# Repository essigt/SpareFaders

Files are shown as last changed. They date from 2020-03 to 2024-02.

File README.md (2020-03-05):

# SpareFaders

A (still work in progress) STM32-BluePill based MA-Style midi controller featuring 60 buttons and 15 faders.

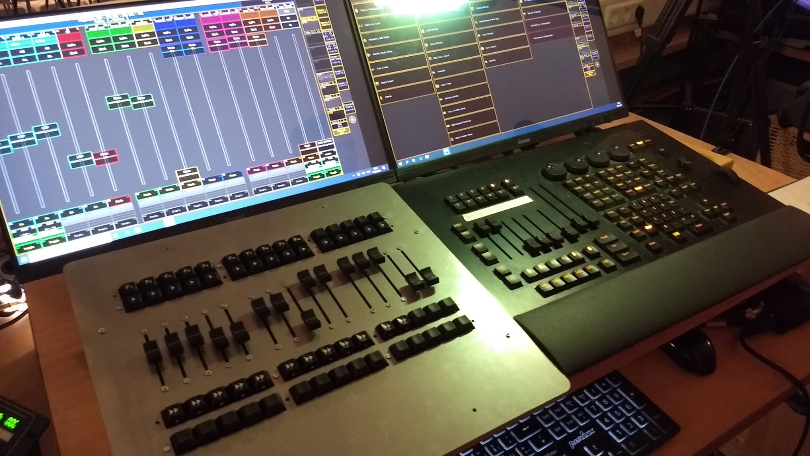
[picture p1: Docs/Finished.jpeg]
Finished prototype


## PCB

The project is made up of two PCB types. A controller PCB and a keys PCB with can be assambled both for the keys above or under the faders.

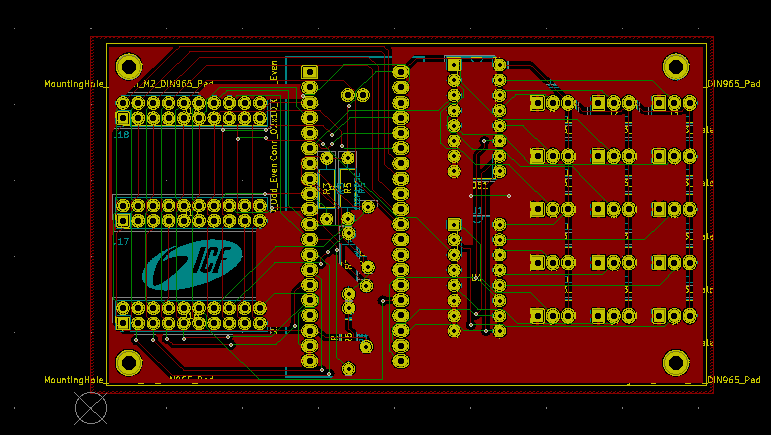
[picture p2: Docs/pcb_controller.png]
Controller PCB


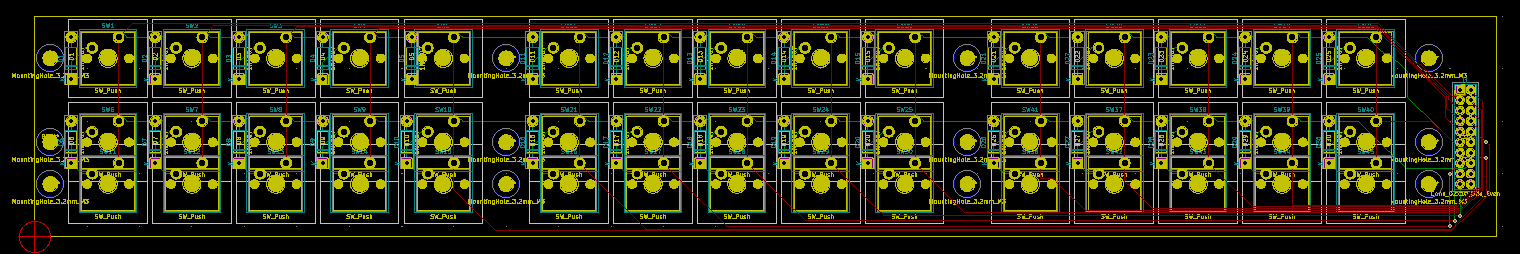
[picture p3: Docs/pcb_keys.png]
Keys PCB


### Assembly

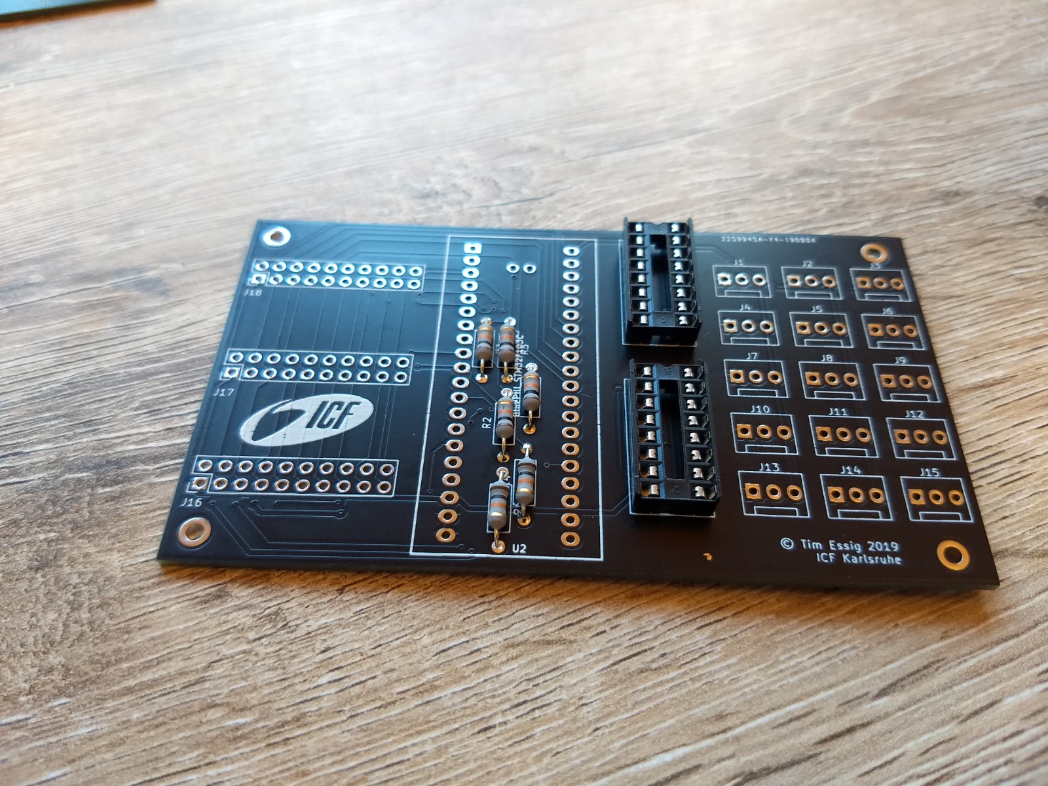
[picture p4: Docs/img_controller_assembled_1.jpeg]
Controller Assembled

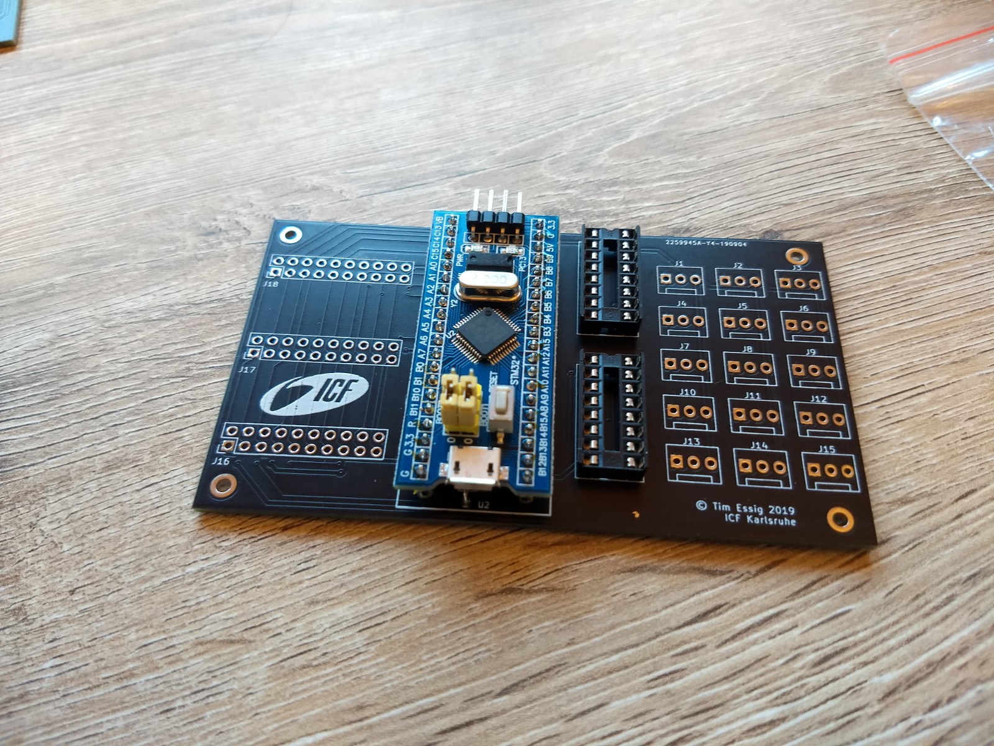
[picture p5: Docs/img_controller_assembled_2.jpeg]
Controller Assembled

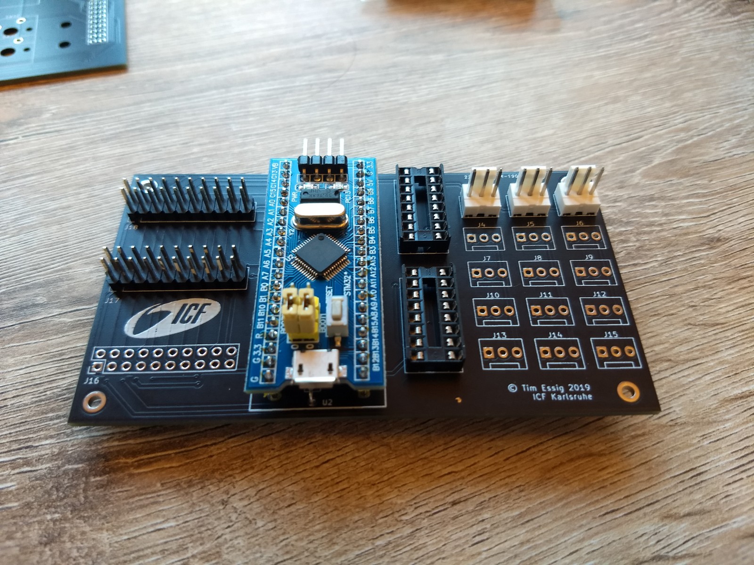
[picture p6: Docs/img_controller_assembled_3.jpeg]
Controller Assembled


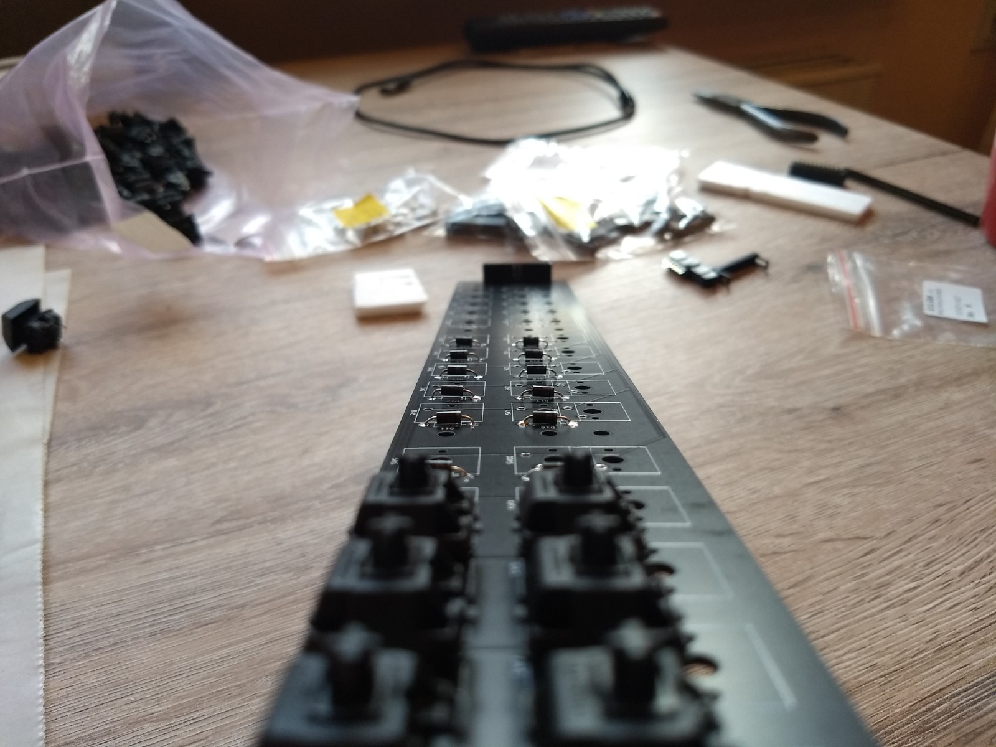
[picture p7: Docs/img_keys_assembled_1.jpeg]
Keys Assembled

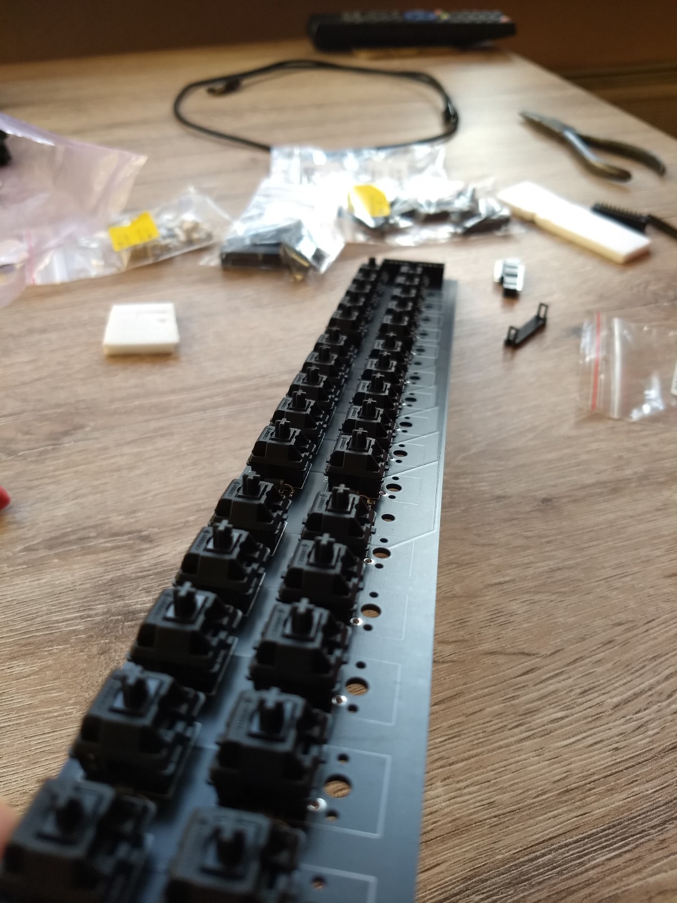
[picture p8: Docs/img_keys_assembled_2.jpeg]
Keys Assembled


## Front Plate

The files for the front plate will be uploaded soon.

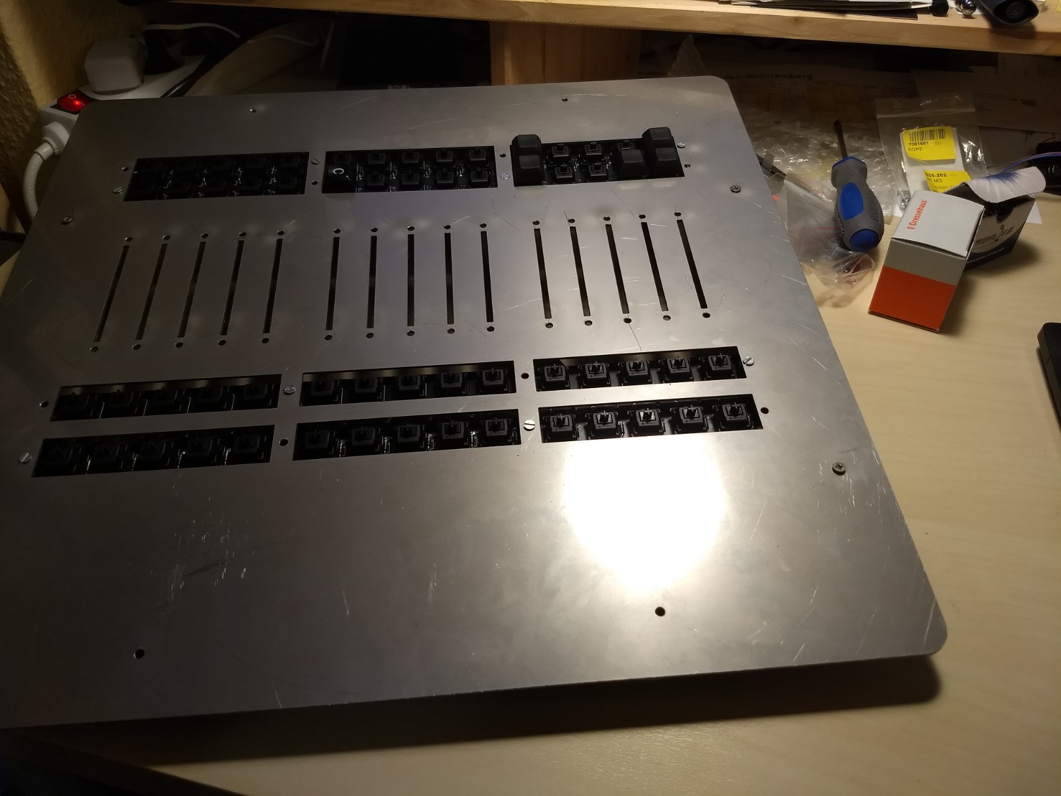
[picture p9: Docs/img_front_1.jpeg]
Front plate


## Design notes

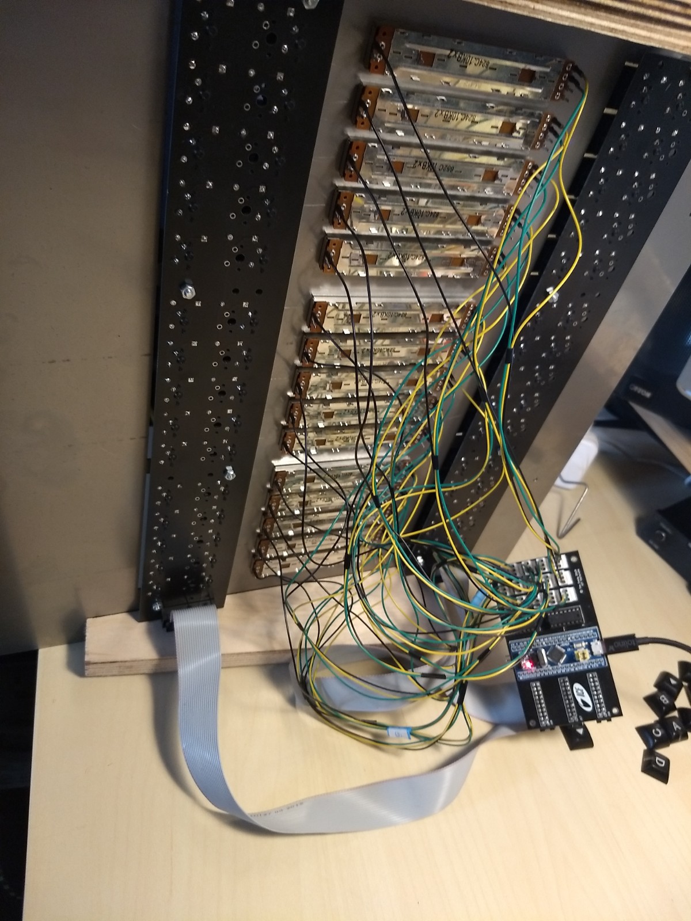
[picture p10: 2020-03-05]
Docs/img_back_1.jpeg

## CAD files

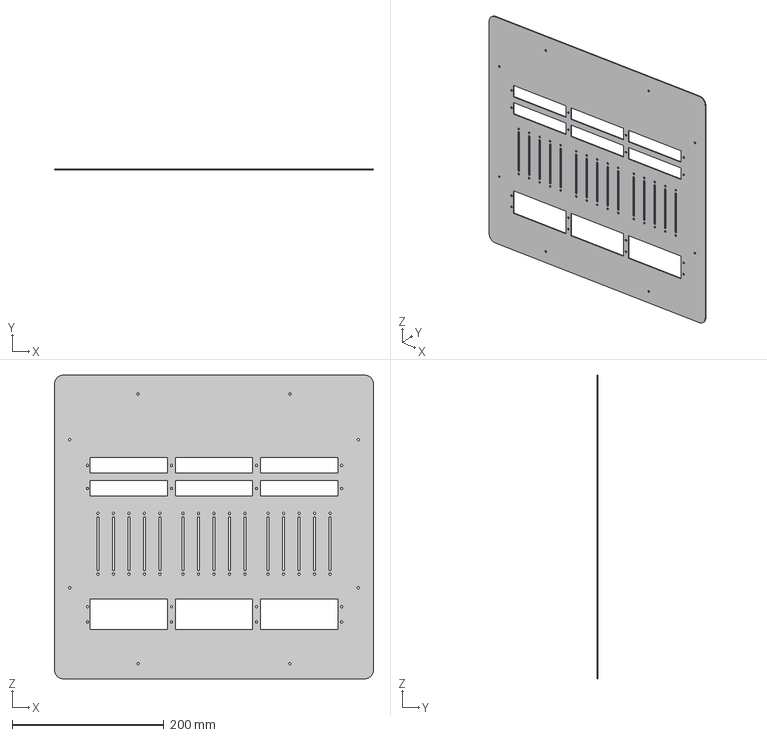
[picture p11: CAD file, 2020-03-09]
Hardware/housing/export/frontplate.step
420.0 x 1.50 x 400.0 mm

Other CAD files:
Hardware/housing/export/frontplate.dxf
Hardware/housing/frontplate.f3d

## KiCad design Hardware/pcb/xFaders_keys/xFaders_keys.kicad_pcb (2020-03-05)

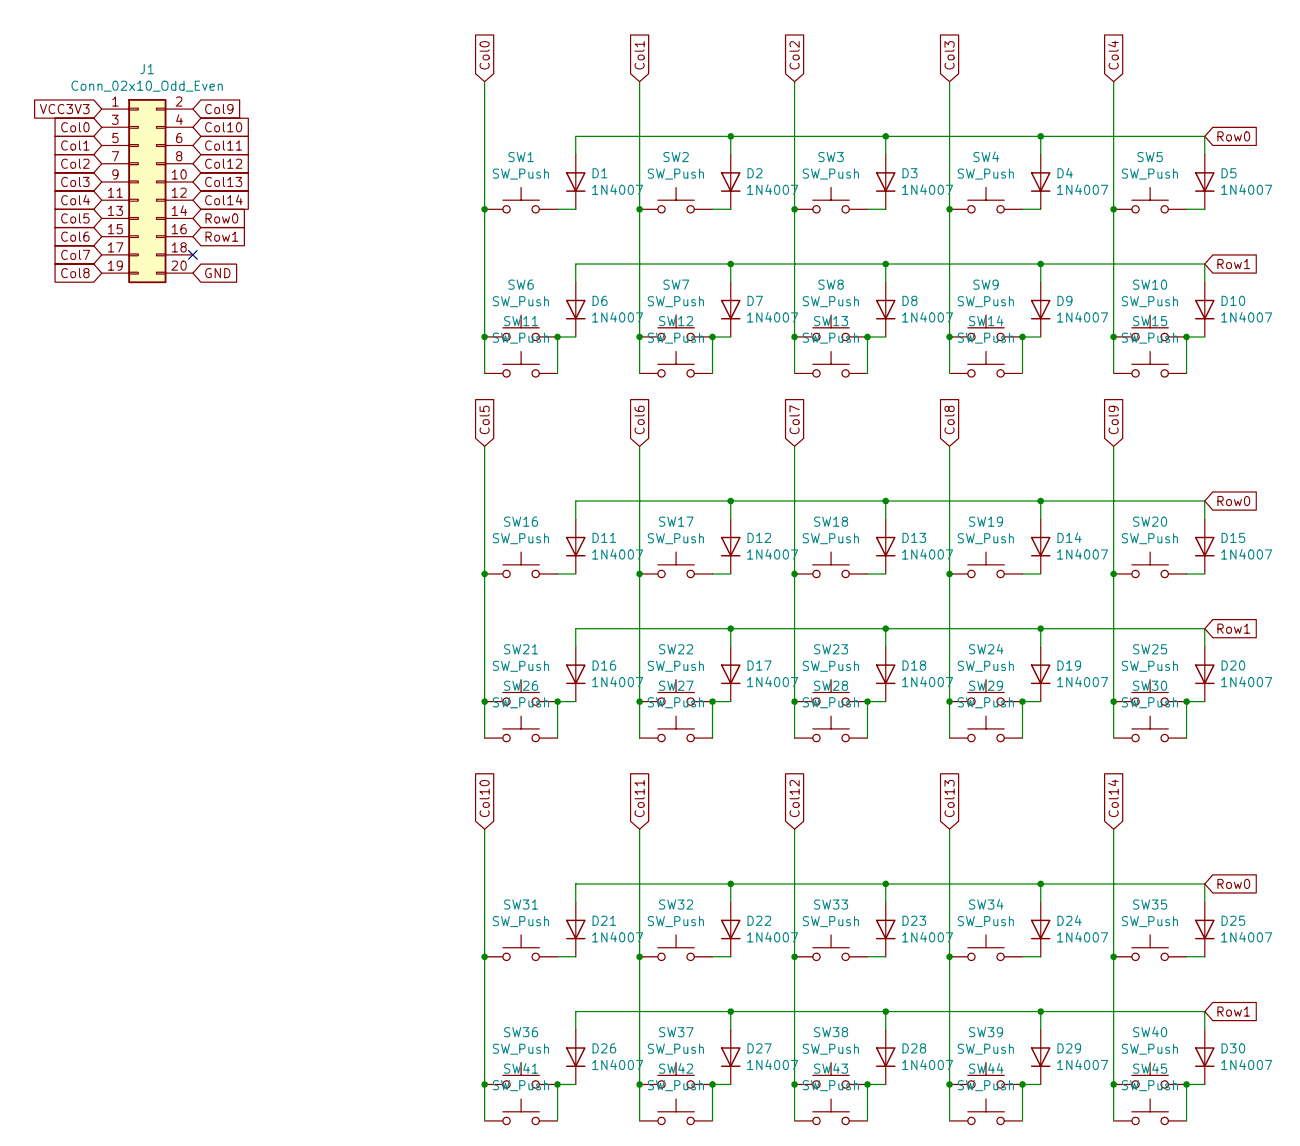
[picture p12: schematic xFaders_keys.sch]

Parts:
D1, D2, D3, D4, D5, D6, D7, D8, D9, D10, D11, D12, D13, D14, D15, D16, D17, D18, D19, D20, D21, D22, D23, D24, D25, D26, D27, D28, D29, D30: 1N4007; D_DO-41_SOD81_P10.16mm_Horizontal
J1: Conn_02x10_Odd_Even; PinHeader_2x10_P2.54mm_Vertical
SW1, SW2, SW3, SW4, SW5, SW6, SW7, SW8, SW9, SW10, SW11, SW12, SW13, SW14, SW15, SW16, SW17, SW18, SW19, SW20, SW21, SW22, SW23, SW24, SW25, SW26, SW27, SW28, SW29, SW30, SW31, SW32, SW33, SW34, SW35, SW36, SW37, SW38, SW39, SW40, SW41, SW42, SW43, SW44, SW45: SW_Push; SW_Cherry_MX_1.00u_PCB

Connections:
Col0: J1.3, SW1.1, SW6.1, SW11.1
Col1: J1.5, SW2.1, SW7.1, SW12.1
Col2: J1.7, SW3.1, SW8.1, SW13.1
Col3: J1.9, SW4.1, SW9.1, SW14.1
Col4: J1.11, SW5.1, SW10.1, SW15.1
Col5: J1.13, SW16.1, SW21.1, SW26.1
Col6: J1.15, SW17.1, SW22.1, SW27.1
Col7: J1.17, SW18.1, SW23.1, SW28.1
Col8: J1.19, SW19.1, SW24.1, SW29.1
Col9: J1.2, SW20.1, SW25.1, SW30.1
Col10: J1.4, SW31.1, SW36.1, SW41.1
Col11: J1.6, SW32.1, SW37.1, SW42.1
Col12: J1.8, SW33.1, SW38.1, SW43.1
Col13: J1.10, SW34.1, SW39.1, SW44.1
Col14: J1.12, SW35.1, SW40.1, SW45.1
GND: J1.20
unnamed: D1.1 (K), SW1.2
unnamed: D2.1 (K), SW2.2
unnamed: D3.1 (K), SW3.2
unnamed: D4.1 (K), SW4.2
unnamed: D5.1 (K), SW5.2
unnamed: D6.1 (K), SW6.2, SW11.2
unnamed: D7.1 (K), SW7.2, SW12.2
unnamed: D8.1 (K), SW8.2, SW13.2
unnamed: D9.1 (K), SW9.2, SW14.2
unnamed: D10.1 (K), SW10.2, SW15.2
unnamed: D11.1 (K), SW16.2
unnamed: D12.1 (K), SW17.2
unnamed: D13.1 (K), SW18.2
unnamed: D14.1 (K), SW19.2
unnamed: D15.1 (K), SW20.2
unnamed: D16.1 (K), SW21.2, SW26.2
unnamed: D17.1 (K), SW22.2, SW27.2
unnamed: D18.1 (K), SW23.2, SW28.2
unnamed: D19.1 (K), SW24.2, SW29.2
unnamed: D20.1 (K), SW25.2, SW30.2
unnamed: D21.1 (K), SW31.2
unnamed: D22.1 (K), SW32.2
unnamed: D23.1 (K), SW33.2
unnamed: D24.1 (K), SW34.2
unnamed: D25.1 (K), SW35.2
unnamed: D26.1 (K), SW36.2, SW41.2
unnamed: D27.1 (K), SW37.2, SW42.2
unnamed: D28.1 (K), SW38.2, SW43.2
unnamed: D29.1 (K), SW39.2, SW44.2
unnamed: D30.1 (K), SW40.2, SW45.2
Row0: D1.2 (A), D2.2 (A), D3.2 (A), D4.2 (A), D5.2 (A), D11.2 (A), D12.2 (A), D13.2 (A), D14.2 (A), D15.2 (A), D21.2 (A), D22.2 (A), D23.2 (A), D24.2 (A), D25.2 (A), J1.14
Row1: D6.2 (A), D7.2 (A), D8.2 (A), D9.2 (A), D10.2 (A), D16.2 (A), D17.2 (A), D18.2 (A), D19.2 (A), D20.2 (A), D26.2 (A), D27.2 (A), D28.2 (A), D29.2 (A), D30.2 (A), J1.16
VCC3V3: J1.1

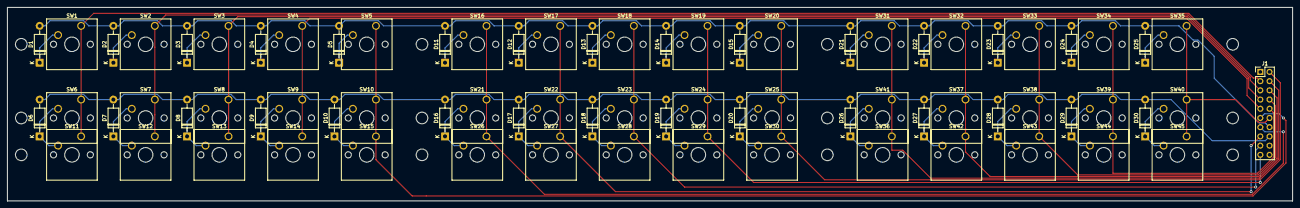
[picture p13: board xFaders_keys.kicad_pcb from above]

Board: 2 copper layers, 354.3 x 53.3 mm, 76 parts (0 on the bottom side), 47 nets.

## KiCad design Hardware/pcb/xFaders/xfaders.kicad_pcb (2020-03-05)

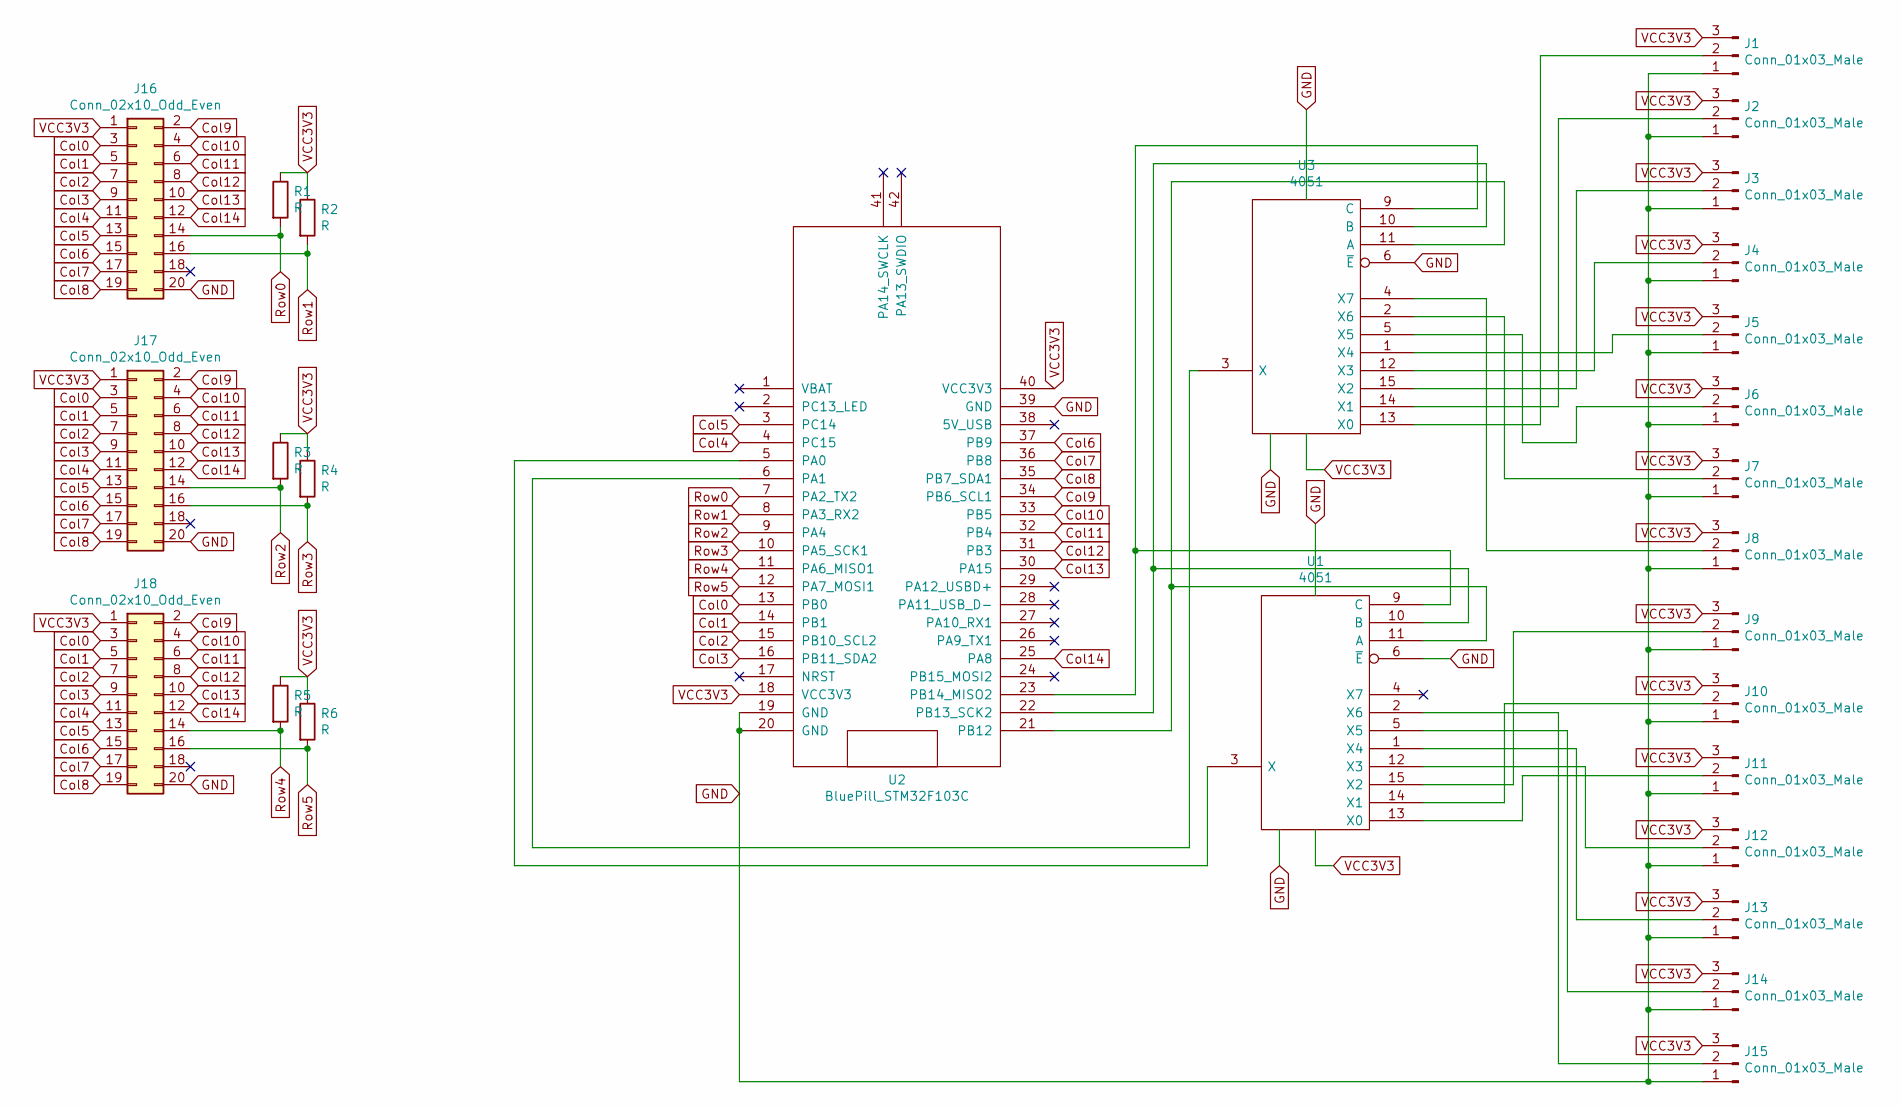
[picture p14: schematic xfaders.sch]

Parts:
J1, J2, J3, J4, J5, J6, J7, J8, J9, J10, J11, J12, J13, J14, J15: Conn_01x03_Male; FanPinHeader_1x03_P2.54mm_Vertical
J16, J17, J18: Conn_02x10_Odd_Even; PinHeader_2x10_P2.54mm_Vertical
R1, R2, R3, R4, R5, R6: R
U1, U3: 4051; DIP-16_W7.62mm_Socket
U2: BluePill_STM32F103C

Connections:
Col0: J16.3, J17.3, J18.3, U2.13 (PB0)
Col1: J16.5, J17.5, J18.5, U2.14 (PB1)
Col2: J16.7, J17.7, J18.7, U2.15 (PB10_SCL2)
Col3: J16.9, J17.9, J18.9, U2.16 (PB11_SDA2)
Col4: J16.11, J17.11, J18.11, U2.4 (PC15)
Col5: J16.13, J17.13, J18.13, U2.3 (PC14)
Col6: J16.15, J17.15, J18.15, U2.37 (PB9)
Col7: J16.17, J17.17, J18.17, U2.36 (PB8)
Col8: J16.19, J17.19, J18.19, U2.35 (PB7_SDA1)
Col9: J16.2, J17.2, J18.2, U2.34 (PB6_SCL1)
Col10: J16.4, J17.4, J18.4, U2.33 (PB5)
Col11: J16.6, J17.6, J18.6, U2.32 (PB4)
Col12: J16.8, J17.8, J18.8, U2.31 (PB3)
Col13: J16.10, J17.10, J18.10, U2.30 (PA15)
Col14: J16.12, J17.12, J18.12, U2.25 (PA8)
GND: J1.1, J2.1, J3.1, J4.1, J5.1, J6.1, J7.1, J8.1, J9.1, J10.1, J11.1, J12.1, J13.1, J14.1, J15.1, J16.20, J17.20, J18.20, U1.6 (~E), U1.7 (VEE), U1.8 (Vss), U2.19 (GND), U2.20 (GND), U2.39 (GND), U3.6 (~E), U3.7 (VEE), U3.8 (Vss)
unnamed: J1.2, U3.13 (X0)
unnamed: J2.2, U3.14 (X1)
unnamed: J3.2, U3.15 (X2)
unnamed: J4.2, U3.12 (X3)
unnamed: J5.2, U3.1 (X4)
unnamed: J6.2, U3.5 (X5)
unnamed: J7.2, U3.2 (X6)
unnamed: J8.2, U3.4 (X7)
unnamed: J9.2, U1.15 (X2)
unnamed: J10.2, U1.14 (X1)
unnamed: J11.2, U1.13 (X0)
unnamed: J12.2, U1.12 (X3)
unnamed: J13.2, U1.1 (X4)
unnamed: J14.2, U1.5 (X5)
unnamed: J15.2, U1.2 (X6)
unnamed: U1.3 (X), U2.5 (PA0)
unnamed: U1.9 (C), U2.23 (PB14_MISO2), U3.9 (C)
unnamed: U1.10 (B), U2.22 (PB13_SCK2), U3.10 (B)
unnamed: U1.11 (A), U2.21 (PB12), U3.11 (A)
unnamed: U2.6 (PA1), U3.3 (X)
Row0: J16.14, R1.2, U2.7 (PA2_TX2)
Row1: J16.16, R2.2, U2.8 (PA3_RX2)
Row2: J17.14, R3.2, U2.9 (PA4)
Row3: J17.16, R4.2, U2.10 (PA5_SCK1)
Row4: J18.14, R5.2, U2.11 (PA6_MISO1)
Row5: J18.16, R6.2, U2.12 (PA7_MOSI1)
VCC3V3: J1.3, J2.3, J3.3, J4.3, J5.3, J6.3, J7.3, J8.3, J9.3, J10.3, J11.3, J12.3, J13.3, J14.3, J15.3, J16.1, J17.1, J18.1, R1.1, R2.1, R3.1, R4.1, R5.1, R6.1, U1.16 (Vdd), U2.18 (VCC3V3), U2.40 (VCC3V3), U3.16 (Vdd)

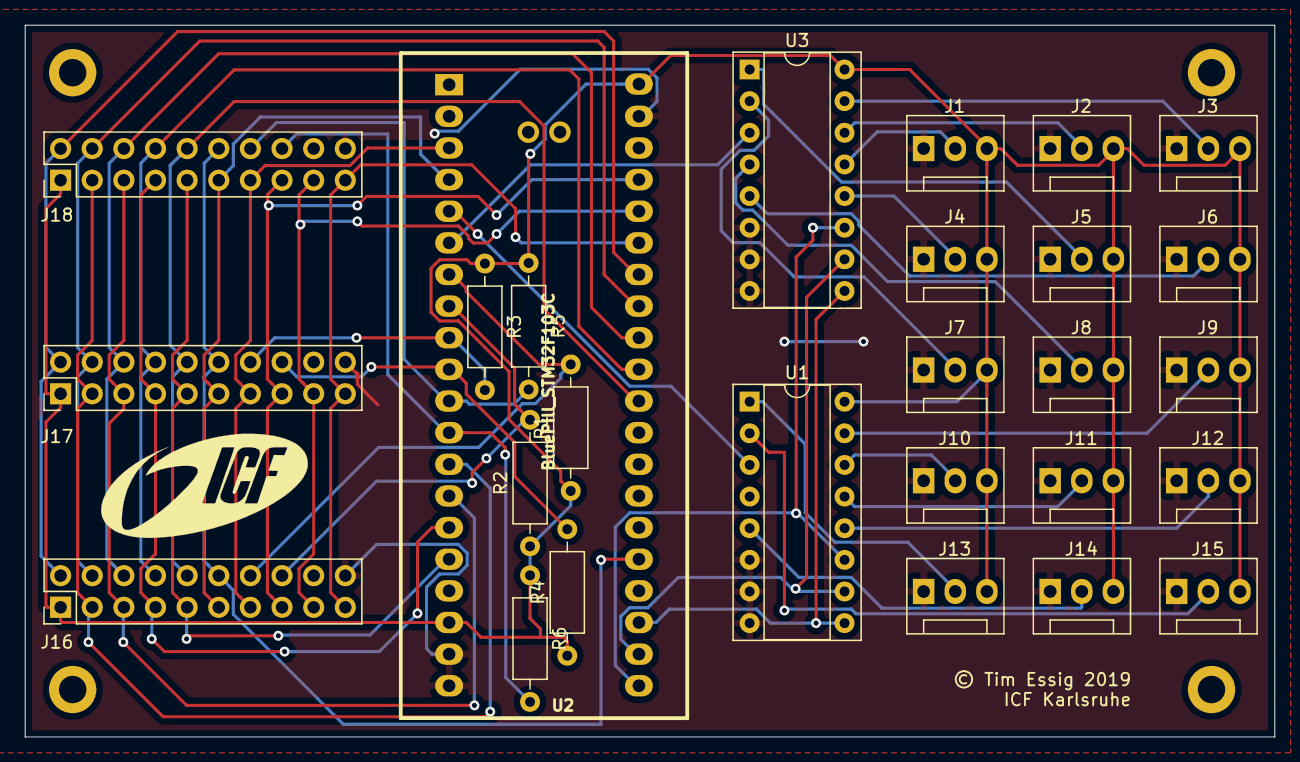
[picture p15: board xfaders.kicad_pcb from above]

Board: 2 copper layers, 100.3 x 57.1 mm, 27 parts (0 on the bottom side), 43 nets.

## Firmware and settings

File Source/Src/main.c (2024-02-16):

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

/* Includes ------------------------------------------------------------------*/
#include "main.h"
#include "usb_device.h"

ADC_HandleTypeDef hadc1;
ADC_HandleTypeDef hadc2;

TIM_HandleTypeDef htim1;

void SystemClock_Config(void);
static void MX_GPIO_Init(void);
static void MX_ADC1_Init(void);
static void MX_ADC2_Init(void);
static void MX_TIM1_Init(void);
/* USER CODE BEGIN 0 */


void resetCols() {
	WRITE_REG(GPIOB->BSRR, GPIO_BSRR_BS0); //COL 0   High
	WRITE_REG(GPIOB->BSRR, GPIO_BSRR_BS1); //COL 1   High
	WRITE_REG(GPIOB->BSRR, GPIO_BSRR_BS10); //COL 2   High
	WRITE_REG(GPIOB->BSRR, GPIO_BSRR_BS11); //COL 3   High
	WRITE_REG(GPIOC->BSRR, GPIO_BSRR_BS14); //COL 4   High
	WRITE_REG(GPIOC->BSRR, GPIO_BSRR_BS15);  //COL 5   High
	WRITE_REG(GPIOB->BSRR, GPIO_BSRR_BS9);  //COL 6   High
	WRITE_REG(GPIOB->BSRR, GPIO_BSRR_BS8); //COL 7   High
	WRITE_REG(GPIOB->BSRR, GPIO_BSRR_BS7); //COL 8   High
	WRITE_REG(GPIOB->BSRR, GPIO_BSRR_BS6);  //COL 9   High
	WRITE_REG(GPIOB->BSRR, GPIO_BSRR_BS5);  //COL10   High
	WRITE_REG(GPIOB->BSRR, GPIO_BSRR_BS4);  //COL11   High
	WRITE_REG(GPIOB->BSRR, GPIO_BSRR_BS3);  //COL12   High
	WRITE_REG(GPIOA->BSRR, GPIO_BSRR_BS15);  //COL13   High
	WRITE_REG(GPIOA->BSRR, GPIO_BSRR_BS8);  //COL14   High
}

void setCol(uint8_t col) {

	if(col == 0) {
		WRITE_REG(GPIOB->BSRR, GPIO_BSRR_BR0); //COL 0
	}

	if(col == 1) {
		WRITE_REG(GPIOB->BSRR, GPIO_BSRR_BR1); //COL 1
	}

	if(col == 2) {
		WRITE_REG(GPIOB->BSRR, GPIO_BSRR_BR10); //COL 2
	}

	if(col == 3) {
		WRITE_REG(GPIOB->BSRR, GPIO_BSRR_BR11); //COL 3
	}

	if(col == 4) {
		WRITE_REG(GPIOC->BSRR, GPIO_BSRR_BR15); //COL 4
	}

	if(col == 5) {
		WRITE_REG(GPIOC->BSRR, GPIO_BSRR_BR14);  //COL 5
	}

	if(col == 6) {
		WRITE_REG(GPIOB->BSRR, GPIO_BSRR_BR9);  //COL 6
	}

	if(col == 7) {
		WRITE_REG(GPIOB->BSRR, GPIO_BSRR_BR8); //COL 7
	}

	if(col == 8) {
		WRITE_REG(GPIOB->BSRR, GPIO_BSRR_BR7); //COL 8
	}

	if(col == 9) {
		WRITE_REG(GPIOB->BSRR, GPIO_BSRR_BR6);  //COL 9
	}

	if(col == 10) {
		WRITE_REG(GPIOB->BSRR, GPIO_BSRR_BR5);  //COL 10
	}

	if(col == 11) {
		WRITE_REG(GPIOB->BSRR, GPIO_BSRR_BR4);  //COL11
	}

	if(col == 12) {
		WRITE_REG(GPIOB->BSRR, GPIO_BSRR_BR3);  //COL12
	}

	if(col == 13) {
		WRITE_REG(GPIOA->BSRR, GPIO_BSRR_BR15);  //COL13
	}

	if(col == 14) {
		WRITE_REG(GPIOA->BSRR, GPIO_BSRR_BR8);  //COL14
	}
}


uint16_t readRow(uint8_t row) {

	if(row == 0) {
		return READ_BIT(GPIOA->IDR, GPIO_BSRR_BS2);
	}

	if(row == 1) {
		return READ_BIT(GPIOA->IDR, GPIO_BSRR_BS3);
	}

	if(row == 2) {
		return READ_BIT(GPIOA->IDR, GPIO_BSRR_BS4);
	}

	if(row == 3) {
		return READ_BIT(GPIOA->IDR, GPIO_BSRR_BS5);
	}

	if(row == 4) {
		return READ_BIT(GPIOA->IDR, GPIO_BSRR_BS6);
	}

	if(row == 5) {
		return READ_BIT(GPIOA->IDR, GPIO_BSRR_BS7);
	}

	return 0;
}


void setDemultiplexFor(uint8_t col) {


	if(col & (1 << 0) ) {
		WRITE_REG(GPIOB->BSRR, GPIO_BSRR_BS12);
	} else {
		WRITE_REG(GPIOB->BSRR, GPIO_BSRR_BR12);
	}

	if(col & (1 << 1) ) {
		WRITE_REG(GPIOB->BSRR, GPIO_BSRR_BS13);
	} else {
		WRITE_REG(GPIOB->BSRR, GPIO_BSRR_BR13);
	}

	if(col & (1 << 2) ) {
		WRITE_REG(GPIOB->BSRR, GPIO_BSRR_BS14);
	} else {
		WRITE_REG(GPIOB->BSRR, GPIO_BSRR_BR14);
	}

}

uint8_t poolADC(uint8_t col) {

	uint8_t adcResult = 0;

	if(col < 8) {
		HAL_ADC_Start(&hadc2);

		HAL_ADC_PollForConversion(&hadc2, 10);
		adcResult = HAL_ADC_GetValue(&hadc2) >> 4;

		HAL_ADC_Stop(&hadc2);
	} else {
		HAL_ADC_Start(&hadc1);

		HAL_ADC_PollForConversion(&hadc1, 10);
		adcResult = HAL_ADC_GetValue(&hadc1) >> 4;

		HAL_ADC_Stop(&hadc1);
	}

	// lower limit
	if(adcResult == 1) {
		adcResult = 0;
	}

	if(adcResult > 50 && adcResult < 255) {
		adcResult+=1;
	}
	if(adcResult > 100 && adcResult < 255) {
		adcResult+=1;
	}
	if(adcResult > 150 && adcResult < 255) {
		adcResult+=1;
	}
	if(adcResult > 200 && adcResult < 255) {
		adcResult+=1;
	}

	return adcResult;
}

void delay_us (uint16_t us) {

	__HAL_TIM_SET_COUNTER(&htim1,0);  // set the counter value a 0
	while (__HAL_TIM_GET_COUNTER(&htim1) < us);  // wait for the counter to reach the us input in the parameter
}


/* USER CODE END 0 */

/**
  * @brief  The application entry point.
  * @retval int
  */
int main(void)
{
  /* USER CODE BEGIN 1 */

	// HID MIDI
	struct midiHID_t {
		uint8_t cable;
		uint8_t midi1;
		uint8_t midi2;
		uint8_t midi3;
	};
	struct midiHID_t midiNodeOn;
	midiNodeOn.cable = 0x09; // CI= Virtual Channel 1 & CIN=Note On
	midiNodeOn.midi1 = 0x90; // 9=Note On / 0=Channel 0
	midiNodeOn.midi2 = 60;  // Note
	midiNodeOn.midi3 = 127; // Velocity=127

	struct midiHID_t midiNodeOff;
	midiNodeOff.cable = 0x08; // CI= Virtual Channel 1 & CIN=Note Off
	midiNodeOff.midi1 = 0x80; // 8=Note Off / 0=Channel 0
	midiNodeOff.midi2 = 60; //Note
	midiNodeOff.midi3 = 127; // Velocity=127

  /* USER CODE END 1 */
  

  /* MCU Configuration--------------------------------------------------------*/

  /* Reset of all peripherals, Initializes the Flash interface and the Systick. */
  HAL_Init();

  /* Configure the system clock */
  SystemClock_Config();

  /* Initialize all configured peripherals */
  MX_GPIO_Init();
  MX_ADC1_Init();
  MX_ADC2_Init();
  MX_USB_DEVICE_Init();
  MX_TIM1_Init();
  /* USER CODE BEGIN 2 */
  HAL_TIM_Base_Start(&htim1);

  #define NUM_ROWS 6
  #define NUM_COLS 15

  uint16_t lastKeyMatrix[NUM_COLS][NUM_ROWS] = {0};
  uint8_t lastFader[NUM_COLS] = {0};


  /* USER CODE END 2 */

  /* Infinite loop */
  /* USER CODE BEGIN WHILE */

  while (1)
  {
	  for(uint8_t col=0; col < NUM_COLS; col++) {
		resetCols();
		setCol(col);

		delay_us(1);

		// Keys
		for(uint8_t row=0; row < NUM_ROWS; row++) {
			uint16_t value = readRow(row);

			if(value != lastKeyMatrix[col][row]) {
				uint8_t note = row * NUM_COLS + col;

				if (value == 0) {
					midiNodeOn.midi2 = note;
					midiNodeOn.midi3 = 127;
					USBD_MIDI_SendReport(&hUsbDeviceFS, &midiNodeOn, 4);
				} else {
					midiNodeOff.midi2 = note;
					midiNodeOff.midi3 = 127;
					USBD_MIDI_SendReport(&hUsbDeviceFS, &midiNodeOff, 4);
				}

				lastKeyMatrix[col][row] = value;
			}
		}

		// Fader
		setDemultiplexFor(col);
		delay_us(1);

		uint8_t adcResult = poolADC(col);

		if(abs(lastFader[col] - adcResult) > 2 || (adcResult == 0 && lastFader[col] != 0)) {
			midiNodeOn.midi2 = 100 + col;
			midiNodeOn.midi3 = adcResult >> 1; // Reduce by one last bit to get a 7 bit resolution (MIDI)

			USBD_MIDI_SendReport(&hUsbDeviceFS, &midiNodeOn, 4);

			lastFader[col] = adcResult;
		}
	}


    /* USER CODE END WHILE */

    /* USER CODE BEGIN 3 */
  }
  /* USER CODE END 3 */
}

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


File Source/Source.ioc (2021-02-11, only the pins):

Mcu.UserName=STM32F103C8Tx
PA0-WKUP.Signal=ADCx_IN0
PA1.Signal=ADCx_IN1
PA11.Signal=USB_DM
PA12.Signal=USB_DP
PA13.Signal=SYS_JTMS-SWDIO
PA14.Signal=SYS_JTCK-SWCLK
PA15.Signal=GPIO_Output
PA2.Signal=GPIO_Input
PA3.Signal=GPIO_Input
PA4.Signal=GPIO_Input
PA5.Signal=GPIO_Input
PA6.Signal=GPIO_Input
PA7.Signal=GPIO_Input
PA8.Signal=GPIO_Output
PB0.Signal=GPIO_Output
PB1.Signal=GPIO_Output
PB10.Signal=GPIO_Output
PB11.Signal=GPIO_Output
PB12.Signal=GPIO_Output
PB13.Signal=GPIO_Output
PB14.Signal=GPIO_Output
PB3.Signal=GPIO_Output
PB4.Signal=GPIO_Output
PB5.Signal=GPIO_Output
PB6.Signal=GPIO_Output
PB7.Signal=GPIO_Output
PB8.Signal=GPIO_Output
PB9.Signal=GPIO_Output
PC14-OSC32_IN.Signal=GPIO_Output
PC15-OSC32_OUT.Signal=GPIO_Output
PD0-OSC_IN.Signal=RCC_OSC_IN
PD1-OSC_OUT.Signal=RCC_OSC_OUT

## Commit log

2020-03-05 Initial commit / CubeMX Files / C Sources
    [xFaders Source Debug.cfg]
2020-03-05 Add KiCad files
    [xFaders_keys-B_Cu.gbr, xFaders_keys-B_Mask.gbr, xFaders_keys-B_Paste.gbr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]
2020-03-08 add frontplate CAD files
    [frontplate.dxf, frontplate.f3d, frontplate.step]
2024-02-16 fix: Bug in in button press detection, debounce faders
    [main.c]
2024-02-16 fix: improve adc timing to avoid interferences between faders
    [main.c]
2024-02-16 fix: avoid faders not reaching its zero point because of hardware tolerances
    [main.c]
2024-02-16 fix: low budget fix for faders not reaching its upper limit because of hardware tolerances
    [main.c]
2024-02-16 fix: avoid fader getting stuck at value 1 instead of reaching 0
    [main.c]

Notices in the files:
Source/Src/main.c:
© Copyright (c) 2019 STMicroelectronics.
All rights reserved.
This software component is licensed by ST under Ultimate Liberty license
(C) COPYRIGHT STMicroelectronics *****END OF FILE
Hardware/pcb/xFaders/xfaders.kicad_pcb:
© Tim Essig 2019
